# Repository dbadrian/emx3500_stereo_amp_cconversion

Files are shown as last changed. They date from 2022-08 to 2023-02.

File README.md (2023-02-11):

# EMX3500 To Stereo Conversion

A "replacement" PCB for the [EMX3500](https://de.yamaha.com/files/download/other_assets/1/324571/EMX3500G.pdf) to convert the L/R-amplification stages and Graphic Equalizer (GEQ) to simple stereo amp.

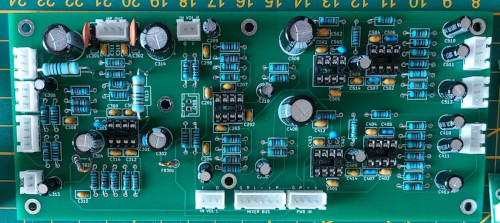
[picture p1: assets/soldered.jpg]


## What is this project?
EMX3500 is an older analog powered mixer by Yamaha, see the below image.
This project separates the mixing part from the amp part of the original product.
To this end, a custom PCB was designed to enable the removal of all unnecessary parts (channels, tape board, various input boards...the massive chassis)

This was required as, looking at the original PCBs (>10 individual PCBs), we find that
* The original PCBs are designed using single layer PCBs with star-grounding (with some PCBs (or parts thereof) directly grounded to the chassis, others via other PCBs)
* Many of mixers PCBs have multiple sub-circuits of different functionalities and its near impossible to remove any part without breaking the complete system

Hence, my conclusion was to refactor the needed circuit paths from a plethora of individual PCBS onto new single purpose PCBs.
This creates a creates a stand-alone stereo amp and, in the future, I can restore the mixer into its own device that can be connected to any stereo amp.

This repository currently contains the KiCad project for the stereo amp related PCB, that can be connected to the original GEQ and amp stages.
The circuit is more or less the original circuit, reduced to its minimal subset required to achieve the desired functionality.
At the same time, the star-grounding is changed in favor for simple 2-layer PCB design with a ground-plane.
I know, I know, hardcore-music aficionados with their bee-wax filled capacitors will cry themselves to sleep hearing this, but I can promise you...I sleep quite comfortably despite this alteration...

Further upgrades also include a small bluetooth module.

> **Note**:
> I am anything but a professional circuit designer. In fact, this was my first complete PCB design with manufacturing...

> **Warning**:
> The headphone related part of the PCB does not what you might think, and will be completely removed/changed in a future revision of this project.

## Why did you destroy a mixer? Why thou!?
By chance I got my hands on a fully-working EMX-3500 for 20EUR at an auction.
I did ***not expect*** this mixer to work at all, but to my surprise all 16-channels, GEQ, DSP board, etc all worked without a hiccup (except maybe slowly deteriorated pots...)
However, I bought it with the intention for salvaging parts for synth-related projects, but clearly this would have been a crime to destroy down to individual parts.

Nevertheless the housing wasn't in the most prestine condition: screws were rusted in (previous owner seemed to have stored it in a garage for an extended time period), one channel's XLR connector was broken in.
Also, and that was the major issue: I didn't have a space for nearly a gigantic and very heavy mixer in my apartment. I didn't plan for it... I was, however, in need for a new stereo amp :).
And the mixer part still exists as is and will be rebuilt into a smaller, independent unit.

## Before and after

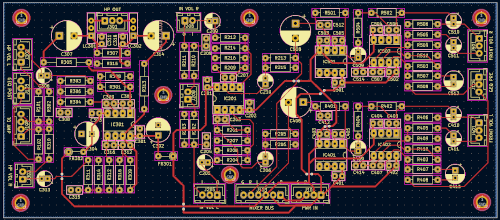
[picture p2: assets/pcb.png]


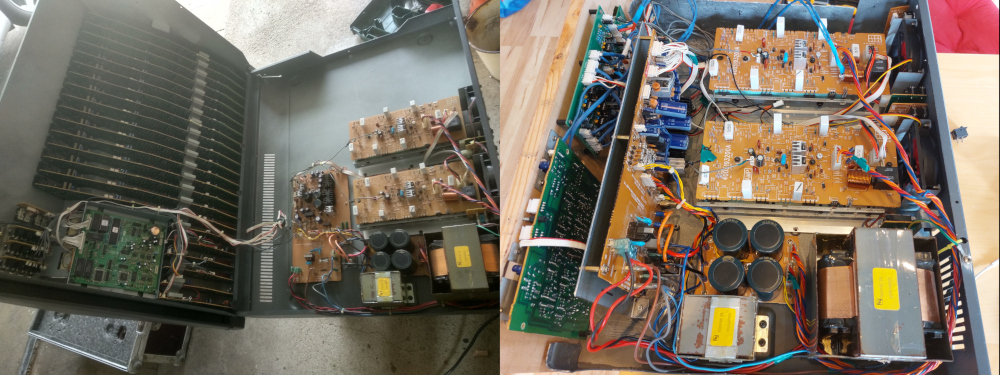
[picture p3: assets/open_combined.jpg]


The case is not totally finished and a temporary housing.
All metal parts are properly grounded.
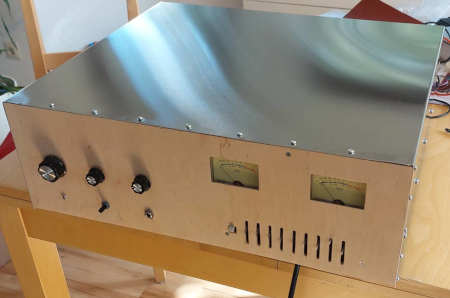
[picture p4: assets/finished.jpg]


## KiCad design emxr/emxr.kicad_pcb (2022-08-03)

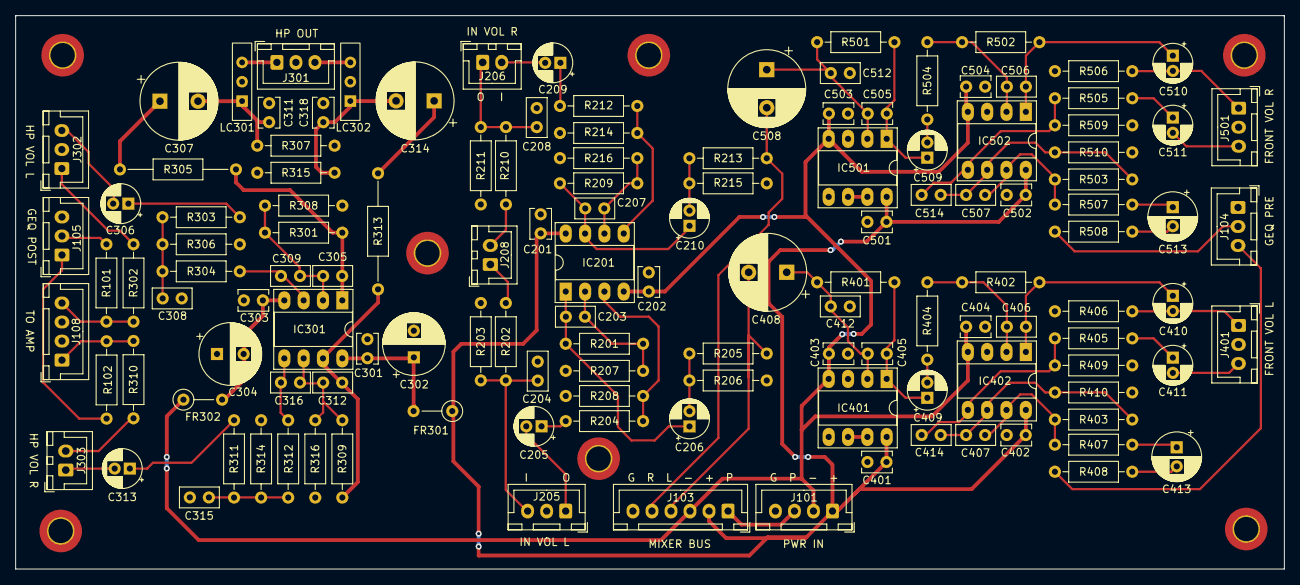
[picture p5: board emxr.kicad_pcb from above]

Board: 2 copper layers, 166.7 x 72.7 mm, 138 parts (0 on the bottom side), 78 nets.

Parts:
C201, C202, C401, C402, C403, C404, C501, C502, C503, C504: 0.01; C_Disc_D3.8mm_W2.6mm_P2.50mm
C203, C204, C207, C208, C305, C308, C309, C312, C315, C316, C414, C514: 100p; C_Disc_D5.0mm_W2.5mm_P2.50mm
C205, C206, C209, C210, C306, C313, C409, C410, C411, C509, C510, C511: 22/50; CP_Radial_D5.0mm_P2.00mm
C301, C303: 0.1; C_Disc_D3.8mm_W2.6mm_P2.50mm
C302, C304: 100/25; CP_Radial_D8.0mm_P3.50mm
C307, C314, C408, C508: 220/25; CP_Radial_D10.0mm_P5.00mm
C311, C318: 0.001; C_Disc_D3.8mm_W2.6mm_P2.50mm
C405, C505: 47p; C_Disc_D3.8mm_W2.6mm_P2.50mm
C406, C407, C506, C507: 150p; C_Disc_D5.0mm_W2.5mm_P2.50mm
C412, C512: 220p; C_Disc_D5.0mm_W2.5mm_P2.50mm
C413, C513: 47/50; CP_Radial_D6.3mm_P2.50mm
FR301, FR302: 10 1/4; R_Axial_DIN0207_L6.3mm_D2.5mm_P5.08mm_Vertical
H101, H102, H103, H104, H105, H106, H107: MH; MountingHole_3.2mm_M3_DIN965_Pad_TopBottom
IC201: NJM4558D; DIP-8_W7.62mm_Socket_LongPads
IC301: NJM4556D; DIP-8_W7.62mm_Socket_LongPads
IC401, IC501: NJM2068DD; DIP-8_W7.62mm_Socket_LongPads
IC402, IC502: NJM4580; DIP-8_W7.62mm_Socket_LongPads
J101: POWER; JST_XH_B4B-XH-A_1x04_P2.50mm_Vertical
J103: Bus Conn; JST_XH_B6B-XH-A_1x06_P2.50mm_Vertical
J104: GEQ_PRE; JST_XH_B3B-XH-A_1x03_P2.50mm_Vertical
J105: GEQ_POST; JST_XH_B3B-XH-A_1x03_P2.50mm_Vertical
J108: AUDIO_OUT; JST_XH_B4B-XH-A_1x04_P2.50mm_Vertical
J205: InpVolL; JST_XH_B3B-XH-A_1x03_P2.50mm_Vertical
J206: InpVolR; JST_XH_B2B-XH-A_1x02_P2.50mm_Vertical
J208: SrcSel; JST_XH_B2B-XH-A_1x02_P2.50mm_Vertical
J301: HPHONES; JST_XH_B3B-XH-A_1x03_P2.50mm_Vertical
J302: HPVolL; JST_XH_B3B-XH-A_1x03_P2.50mm_Vertical
J303: HPVolR; JST_XH_B2B-XH-A_1x02_P2.50mm_Vertical
J401, J501: FrontVolL; JST_XH_B3B-XH-A_1x03_P2.50mm_Vertical
LC301, LC302: 270p; LCL_EMX
R101, R102, R408, R508: 10; R_Axial_DIN0207_L6.3mm_D2.5mm_P10.16mm_Horizontal
R201, R209, R410, R510: 15k; R_Axial_DIN0207_L6.3mm_D2.5mm_P10.16mm_Horizontal
R202, R204, R210, R212, R302, R310, R405, R505: 100; R_Axial_DIN0207_L6.3mm_D2.5mm_P10.16mm_Horizontal
R203, R206, R211, R215, R409, R509: 47k; R_Axial_DIN0207_L6.3mm_D2.5mm_P10.16mm_Horizontal
R205, R213, R401, R501: 27k; R_Axial_DIN0207_L6.3mm_D2.5mm_P10.16mm_Horizontal
R207, R216, R301, R308, R309, R316, R402, R404, R502, R504: 10k; R_Axial_DIN0207_L6.3mm_D2.5mm_P10.16mm_Horizontal
R208, R214, R306, R314: 18k; R_Axial_DIN0207_L6.3mm_D2.5mm_P10.16mm_Horizontal
R303, R304, R311, R312: 220; R_Axial_DIN0207_L6.3mm_D2.5mm_P10.16mm_Horizontal
R305, R313: 100/1W; R_Axial_DIN0207_L6.3mm_D2.5mm_P15.24mm_Horizontal
R307, R315, R406, R506: 100k; R_Axial_DIN0207_L6.3mm_D2.5mm_P10.16mm_Horizontal
R403, R503: 11k; R_Axial_DIN0207_L6.3mm_D2.5mm_P10.16mm_Horizontal
R407, R507: 330; R_Axial_DIN0207_L6.3mm_D2.5mm_P10.16mm_Horizontal

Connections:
+15V: C201.2, C401.2, C402.2, C501.2, C502.2, FR301.1, IC201.8 (V+), IC401.8 (V+), IC402.8 (V+), IC501.8 (V+), IC502.8 (V+), J101.1, J103.2
-15V: C202.1, C403.1, C404.1, C503.1, C504.1, FR302.1, IC201.4 (V-), IC401.4 (V-), IC402.4 (V-), IC501.4 (V-), IC502.4 (V-), J101.2, J103.3
/Stereo Channel L/POT_FRONT_VOL_L_POST: C411.2, J401.3
/Stereo Channel L/POT_FRONT_VOL_L_PRE: C410.2, J401.1, R406.1
/Stereo Channel R/POT_FRONT_VOL_L_POST: C511.2, J501.3
/Stereo Channel R/POT_FRONT_VOL_L_PRE: C510.2, J501.1, R506.1
BUS_L: C408.2, J103.4, R205.1
BUS_R: C508.2, J103.5, R213.1
GND: C201.1, C202.2, C204.2, C208.2, C301.1, C302.2, C303.2, C304.1, C308.2, C311.2, C315.2, C318.2, C401.1, C402.1, C403.2, C404.2, C412.2, C501.1, C502.1, C503.2, C504.2, C512.2, H101.1, H102.1, H103.1, H104.1, H105.1, H106.1, H107.1, IC401.3 (+), IC401.5 (+), IC402.3 (+), IC501.3 (+), IC501.5 (+), IC502.3 (+), J101.4, J103.6, J104.1, J105.3, J108.2, J108.3, J205.2, J301.2, J302.2, J401.2, J501.2, LC301.2, LC302.2, R203.1, R206.2, R207.2, R208.2, R211.1, R214.2, R215.2, R216.2, R306.2, R307.2, R308.2, R314.2, R315.2, R316.2, R406.2, R409.1, R410.1, R506.2, R509.1, R510.1
unnamed: C203.1, IC201.2 (-), R201.1, R207.1
unnamed: C203.2, C206.1, IC201.1, R201.2
unnamed: C204.1, J205.3, R202.1, R203.2
unnamed: C205.1, R204.1
unnamed: C205.2, J205.1
unnamed: C206.2, R205.2, R206.1
unnamed: C207.1, IC201.6 (-), R209.1, R216.1
unnamed: C207.2, C210.1, IC201.7, R209.2
unnamed: C208.1, J206.1, R210.1, R211.2
unnamed: C209.1, R212.1
unnamed: C209.2, J206.2
unnamed: C210.2, R213.2, R215.1
unnamed: C301.2, C302.1, FR301.2, IC301.8 (V+)
unnamed: C303.1, C304.2, FR302.2, IC301.4 (V-)
unnamed: C305.1, C309.2, IC301.2 (-), R301.1, R308.1
unnamed: C305.2, IC301.1, R301.2, R305.1
unnamed: C306.1, R303.1
unnamed: C306.2, J302.3
unnamed: C307.1, R305.2
unnamed: C307.2, C311.1, LC301.1, R307.1
unnamed: C308.1, R303.2, R304.1, R306.1
unnamed: C309.1, IC301.3 (+), R304.2
unnamed: C312.1, C316.2, IC301.6 (-), R309.1, R316.1
unnamed: C312.2, IC301.7, R309.2, R313.1
unnamed: C313.1, R311.1
unnamed: C313.2, J303.1
unnamed: C314.1, R313.2
unnamed: C314.2, C318.1, LC302.1, R315.1
unnamed: C315.1, R311.2, R312.1, R314.1
unnamed: C316.1, IC301.5 (+), R312.2
unnamed: C405.1, C408.1, C412.1, IC401.2 (-), R401.1
unnamed: C405.2, C409.1, IC401.1, R401.2
unnamed: C406.1, IC402.2 (-), R402.1, R404.2
unnamed: C406.2, C410.1, IC402.1, R402.2
unnamed: C407.1, C414.2, IC402.6 (-), R403.1, R410.2
unnamed: C407.2, IC402.7, R403.2, R407.1
unnamed: C409.2, R404.1
unnamed: C411.1, R405.1
unnamed: C413.1, R407.2
unnamed: C413.2, R408.1
unnamed: C414.1, IC402.5 (+), R405.2, R409.2
unnamed: C505.1, C508.1, C512.1, IC501.2 (-), R501.1
unnamed: C505.2, C509.1, IC501.1, R501.2
unnamed: C506.1, IC502.2 (-), R502.1, R504.2
unnamed: C506.2, C510.1, IC502.1, R502.2
unnamed: C507.1, C514.2, IC502.6 (-), R503.1, R510.2
unnamed: C507.2, IC502.7, R503.2, R507.1
unnamed: C509.2, R504.1
unnamed: C511.1, R505.1
unnamed: C513.1, R507.2
unnamed: C513.2, R508.1
unnamed: C514.1, IC502.5 (+), R505.2, R509.2
unnamed: IC201.3 (+), R204.2, R208.1
unnamed: IC201.5 (+), R212.2, R214.1
unnamed: IC401.6 (-), IC401.7
unnamed: IC501.6 (-), IC501.7
unnamed: J105.1, R102.1
unnamed: J105.2, R101.1
unnamed: J301.1, LC301.3
unnamed: J301.3, LC302.3
unnamed: J302.1, R302.2
unnamed: J303.2, R310.2
PHANTOM_PW: J101.3, J103.1
SELECTED_L: J208.1, R202.2
SELECTED_R: J208.2, R210.2
SINGAL_L_POST_GEQ: J108.4, R101.2, R302.1
SINGAL_L_PRE_GEQ: J104.3, R408.2
SINGAL_R_POST_GEQ: J108.1, R102.2, R310.1
SINGAL_R_PRE_GEQ: J104.2, R508.2

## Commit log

2022-07-13 add initial schematics for the new front panel pcb
    [audio_selection.kicad_sch, emxr.kicad_pcb, emxr.kicad_sch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]
2022-07-20 finish footprints, starting on component placement
    [audio_selection.kicad_sch, emxr.kicad_pcb, emxr.kicad_sch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]
2022-07-21 progress on layouting
    [emxr.kicad_pcb]
2022-07-21 replicated layout
    [audio_selection.kicad_sch, emxr.kicad_pcb, emxr.kicad_sch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]
2022-07-21 more routing and reshuffling
    [audio_selection.kicad_sch, emxr.kicad_pcb, emxr.kicad_sch]
2022-07-21 first pcb draft
    [audio_selection.kicad_sch, connectors.kicad_sch, emxr.kicad_pcb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]
2022-07-21 fix some missing routes in pcb
    [emxr.kicad_pcb]
2022-07-21 change connector layout back for power
    [emxr.kicad_pcb]
2022-07-22 finished pcb draft
    [emxr.kicad_pcb, emxr.kicad_sch]
2022-07-24 more cleaning up/finishing touches
    [emxr-B_Cu.gbr, emxr-B_Mask.gbr, emxr-B_Paste.gbr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]
2022-08-03 add bom
2022-08-03 gerbers update
    [emxr-B_Cu.gbr, emxr-B_Mask.gbr, emxr-B_Paste.gbr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]
2023-02-11 Add some doc
    [connectors.kicad_sch]
2023-02-11 Add some image assets
    [connectors.kicad_sch]
